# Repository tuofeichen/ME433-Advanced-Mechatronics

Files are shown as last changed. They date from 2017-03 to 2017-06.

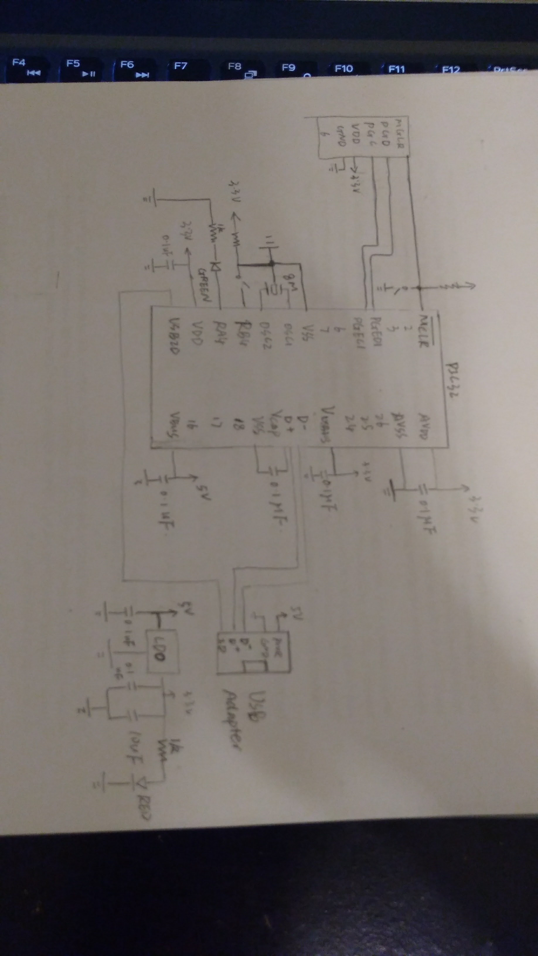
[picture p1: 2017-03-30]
HW1/HW1_Schematic.jpg

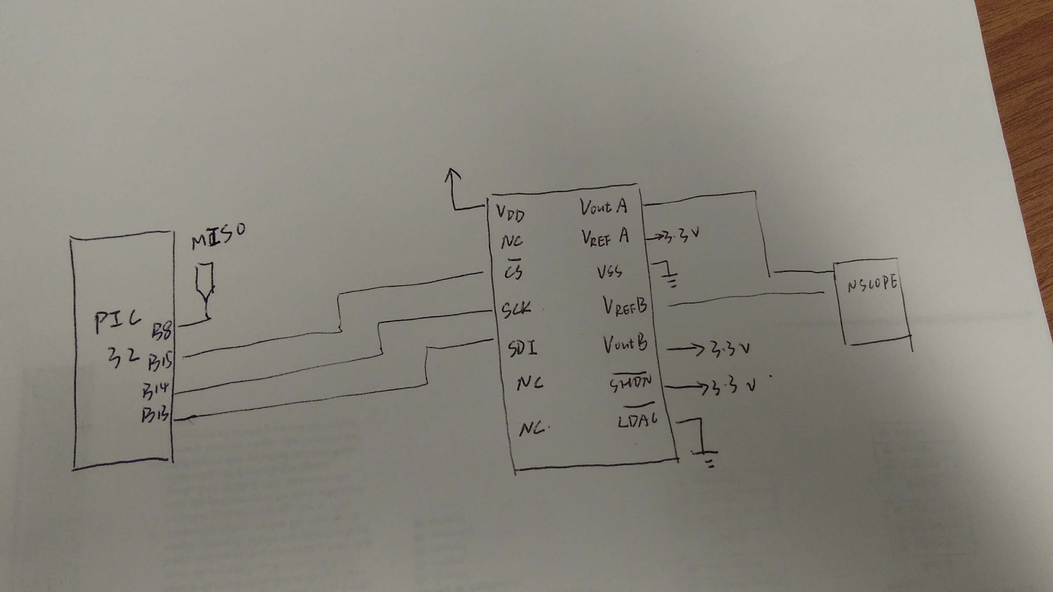
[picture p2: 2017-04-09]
HW4/dac.jpg

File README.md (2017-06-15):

# ME433-Advanced-Mechatronics
This is a course repo for ME 433 Advanced Mechatronics at Northwestern. In this class, I build a mobile robot that's controlled by an Android phone to follow a colored line. 

I use the camera of the phone to track the line and I use a PIC32 microcontroller to control the motor. The phone and the PIC32 communicates via USB. 

The final java code for the android phone is in TechCupAndroid folder while the final C code for the PIC32 is in the TechCupPIC folder. 

I laser cut and 3D printed all the mounting fixture (including suspension and wheels). 

See below as the final demonstration. 

(https://www.youtube.com/watch?v=JEivp6OKbOI)

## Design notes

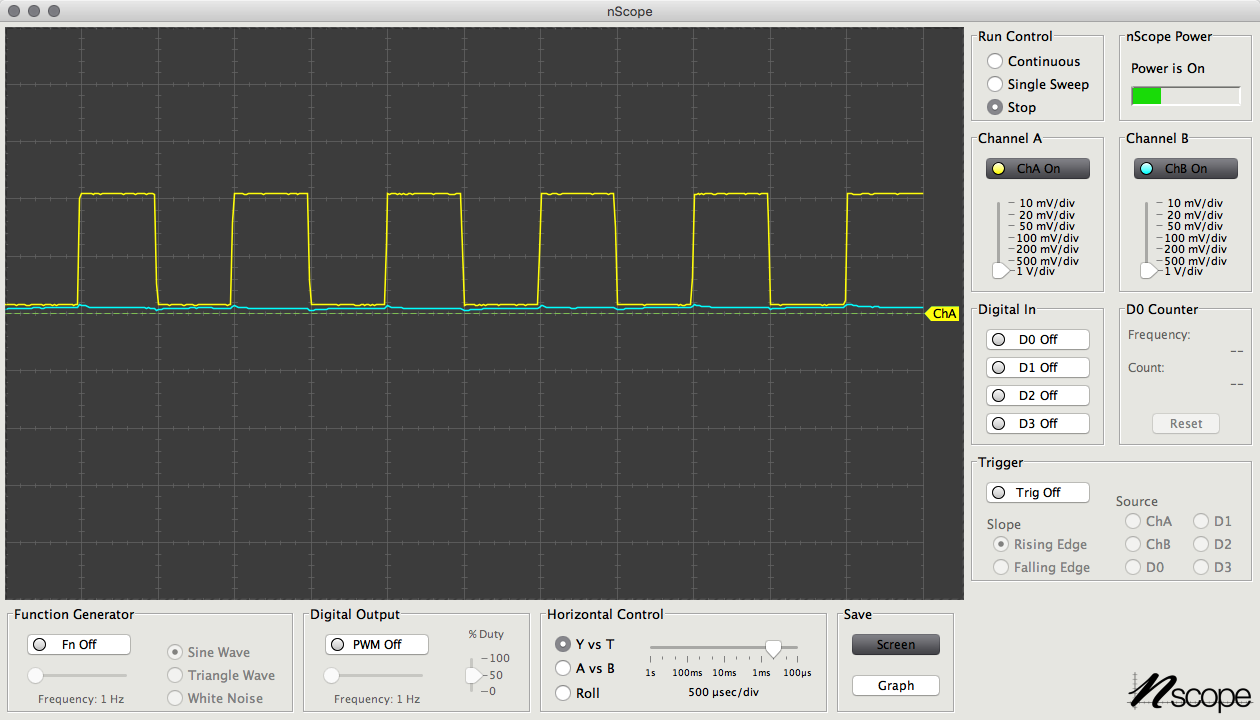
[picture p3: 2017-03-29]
HW1/HW1_LED_Signal.png

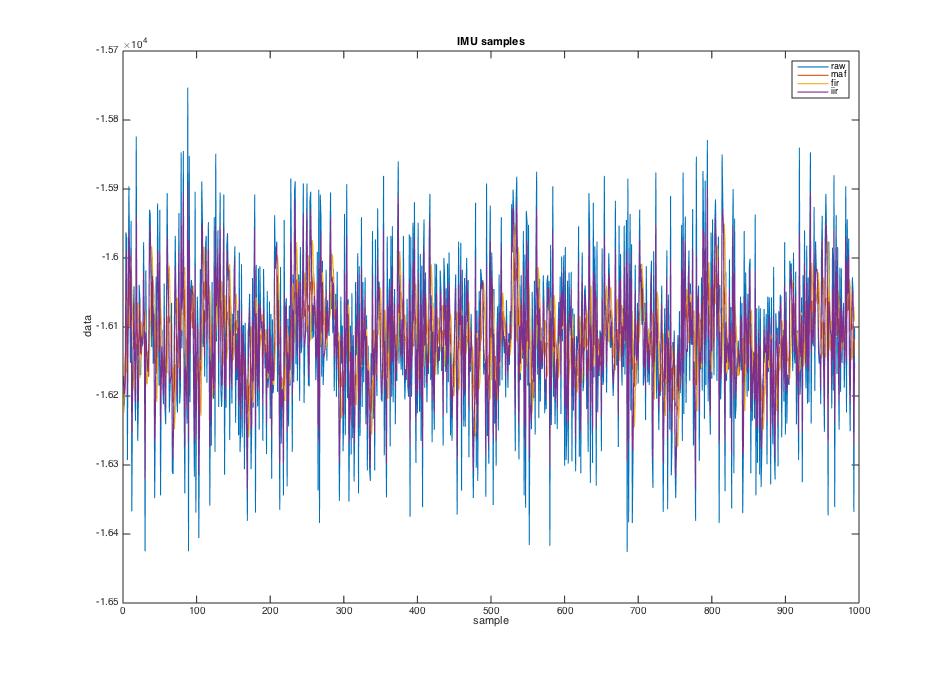
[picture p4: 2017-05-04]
HW9/all_in_one6.jpg

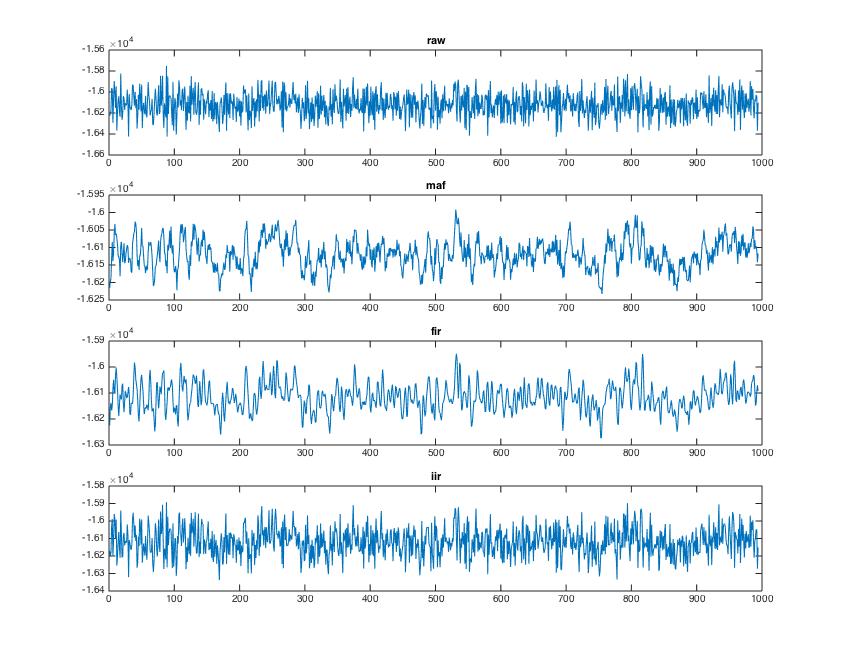
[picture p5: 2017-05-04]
HW9/sep6.jpg

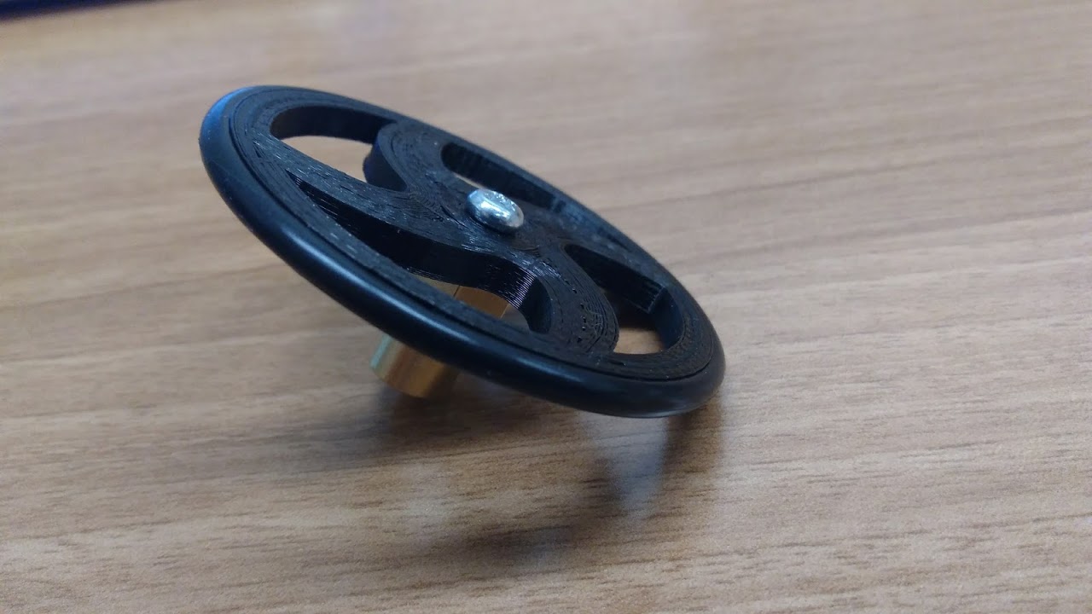
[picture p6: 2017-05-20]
HW16/wheel.jpg

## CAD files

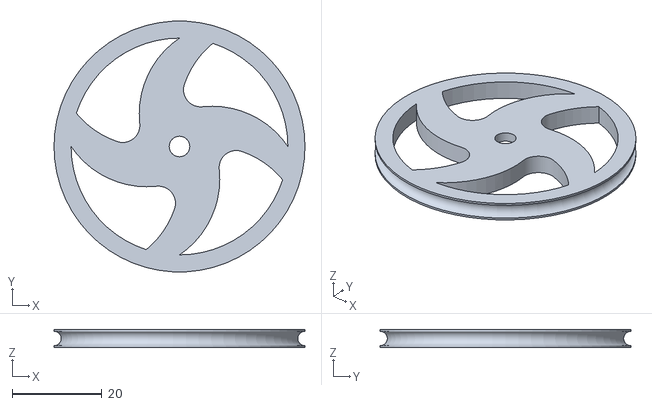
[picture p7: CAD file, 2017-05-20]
HW15/Wheel.stl
55.9 x 55.8 x 4.06

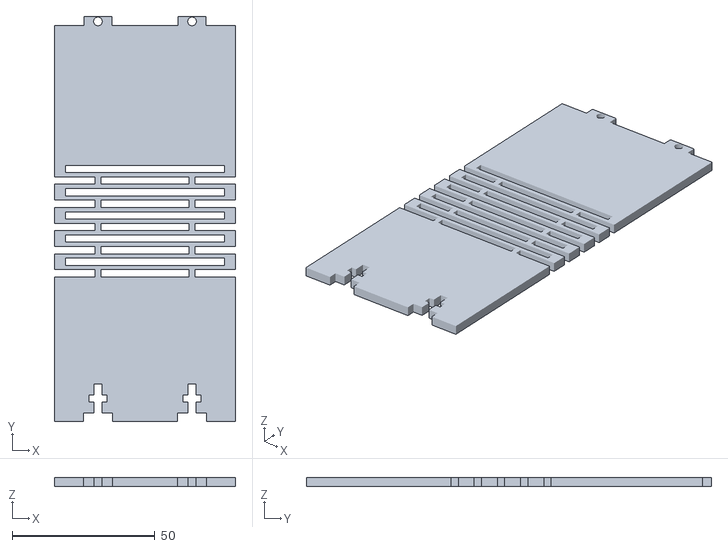
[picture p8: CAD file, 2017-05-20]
HW15/box_revolved.stl
63.5 x 142.2 x 3.17

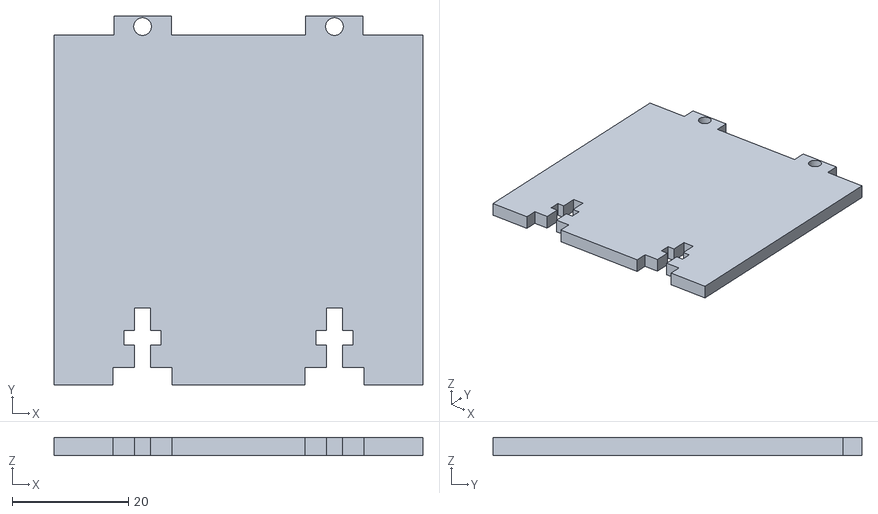
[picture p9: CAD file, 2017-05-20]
HW15/box_side.stl
63.5 x 63.5 x 3.17

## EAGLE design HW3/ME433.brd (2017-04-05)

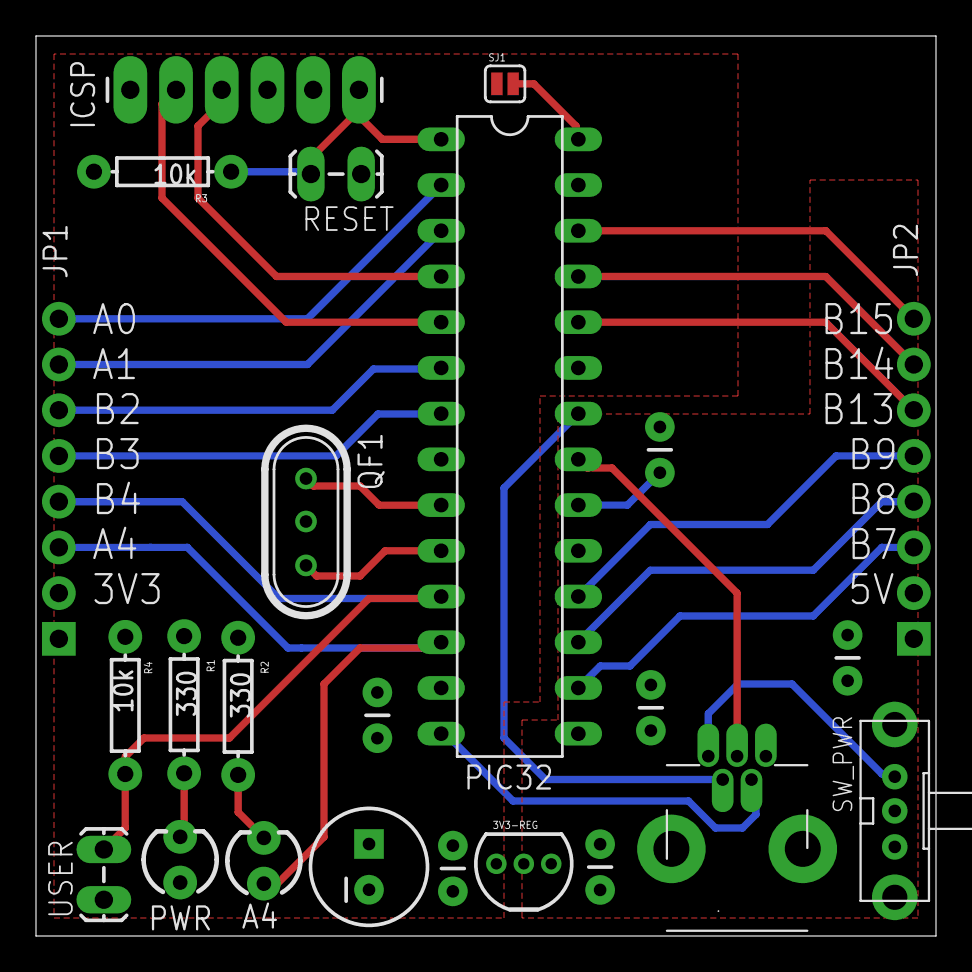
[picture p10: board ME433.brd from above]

Board: 2 copper layers, 50.0 x 50.0 mm, 24 parts (0 on the bottom side), 28 nets.

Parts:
3V3-REG: 3V3-REG-TO92; TO-92
A4: LED3MM
C1, C2, C3, C9, C10: 0.1uF; CAP-PTH-SMALL
C4: 10uF; CAP-PTH-SMALL
C6: 10uF; CPOL-RADIAL-100UF-25V
CN1: USB-MINIB-THM-MOLEX
ICSP: 1X06_LONGPADS
JP1, JP2: 1X08
PIC32: PIC32MX250F128B-DIP; DIP28
PWR: LED3MM
QF1: 8M; HC49U
R1, R2: 330; AXIAL-0.3
R3, R4: 10k; AXIAL-0.3
RESET: PUSH_BUT; 1X02_LOCK_LONGPADS
SJ1: SOLDERJUMPERNC; SJ_2S
SW_PWR: EG1213
USER: PUSH_BUT; 1X02_LOCK_LONGPADS

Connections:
5V: 3V3-REG.2, C2.1, C3.2, C9.2, JP2.2, PIC32.15, SW_PWR.2
!MCLR: ICSP.1, PIC32.1, R3.P$1, RESET.2
+3V3: 3V3-REG.1, C1.1, C6.1, C10.2, ICSP.2, JP1.2, PIC32.13, PIC32.23, PWR.A, R3.P$2, R4.P$2, SJ1.1
AVDD: PIC32.28, SJ1.2
GND: 3V3-REG.3, C1.2, C2.2, C3.1, C4.2, C6.2, C9.1, C10.1, CN1.GND, ICSP.3, JP1.1, JP2.1, PIC32.8, PIC32.19, PIC32.27, QF1.2, R1.P$1, R2.P$1, RESET.1, USER.1
unnamed: PIC32.9, QF1.1
unnamed: PIC32.10, QF1.3
unnamed: A4.K, R2.P$2
unnamed: C4.1, PIC32.20
unnamed: PWR.K, R1.P$2
unnamed: CN1.VBUS, SW_PWR.3
PGC: ICSP.5, PIC32.5
PGD: ICSP.4, PIC32.4
RA0: JP1.8, PIC32.2
RA1: JP1.7, PIC32.3
RA4: A4.A, JP1.3, PIC32.12
RB2: JP1.6, PIC32.6
RB3: JP1.5, PIC32.7
RB4: JP1.4, PIC32.11, R4.P$1, USER.2
RB7: JP2.3, PIC32.16
RB8: JP2.4, PIC32.17
RB9: JP2.5, PIC32.18
RB13: JP2.6, PIC32.24
RB14: JP2.7, PIC32.25
RB15: JP2.8, PIC32.26
USB_D+: CN1.D+, PIC32.21
USB_D-: CN1.D-, PIC32.22
USB_ID: CN1.ID, PIC32.14

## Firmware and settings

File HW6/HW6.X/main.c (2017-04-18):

#include<xc.h>           // processor SFR definitions
#include<sys/attribs.h>  // __ISR macro
#include "tft.h"

// DEVCFG0
#pragma config DEBUG  = OFF         // no debugging
#pragma config JTAGEN = OFF         // no jtag
#pragma config ICESEL = ICS_PGx1    // use PGED1 and PGEC1
#pragma config PWP    = OFF         // no write protect
#pragma config BWP    = OFF         // no boot write protect
#pragma config CP     = OFF         // no code protect

// DEVCFG1
#pragma config FNOSC    = PRIPLL       // use primary oscillator with pll
#pragma config FSOSCEN  = OFF          // turn off secondary oscillator
#pragma config IESO     = OFF          // no switching clocks
#pragma config POSCMOD  = HS           // high speed crystal mode
#pragma config OSCIOFNC = OFF          // free up secondary osc pins
#pragma config FPBDIV   = DIV_1        // divide CPU freq by 1 for peripheral bus clock
#pragma config FCKSM    = CSDCMD       // do not enable clock switch
#pragma config WDTPS    = PS1048576    // slowest wdt
#pragma config WINDIS   = OFF          // no wdt window
#pragma config FWDTEN   = OFF          // wdt off by default
#pragma config FWDTWINSZ = WINSZ_25    // wdt window at 25%

// DEVCFG2 - get the CPU clock to 48MHz
#pragma config FPLLIDIV = DIV_2     // divide input clock to be in range 4-5MHz
#pragma config FPLLMUL  = MUL_24    // multiply clock after FPLLIDIV
#pragma config FPLLODIV = DIV_2     // divide clock after FPLLMUL to get 48MHz
#pragma config UPLLIDIV = DIV_2     // divider for the 8MHz input clock, then multiply by 12 to get 48MHz for USB
#pragma config UPLLEN   = ON        // USB clock on

// DEVCFG3
#pragma config USERID       = 0x0000  // some 16bit userid, doesn't matter what
#pragma config PMDL1WAY     = OFF     // allow multiple reconfigurations
#pragma config IOL1WAY      = OFF     // allow multiple reconfigurations
#pragma config FUSBIDIO     = ON      // USB pins controlled by USB module
#pragma config FVBUSONIO    = ON      // USB BUSON controlled by USB module


volatile int i = 0;

void __ISR(_TIMER_2_VECTOR, IPL7SOFT)refreshScreen(void)
{
    char hello [100];
    sprintf(hello, "hello ME433! %d  ",i);         
    drawStr (28, 32,  hello,   0xF0E2);
    drawRect(14, 50,  i ,  20 ,0xF0E2);
    PORTAINV = 0x0010;
    if (i++ == 100)
    {
        drawRect(14 ,50,  100 ,  20 , BACKGROUND);
        i = 0;
    }           
    
    IFS0bits.T2IF = 0;          // clear interrupt flag 2!
};

int main() {

    __builtin_disable_interrupts();

    // set the CP0 CONFIG register to indicate that kseg0 is cacheable (0x3)
    __builtin_mtc0(_CP0_CONFIG, _CP0_CONFIG_SELECT, 0xa4210583);

    // 0 data RAM access wait states
    BMXCONbits.BMXWSDRM = 0x0;

    // enable multi vector interrupts
    INTCONbits.MVEC = 0x1;

    // disable JTAG to get pins back
    DDPCONbits.JTAGEN = 0;

    // do your TRIS and LAT commands here
    TRISAbits.TRISA4 = 0; //set A4 to be output (Green LED)
    TRISBbits.TRISB4 = 1; //set B4 to be input  (debug button)
    _CP0_SET_COUNT(0);
    
    SPI1_init();
    LCD_init();
    timer_init();
    
    __builtin_enable_interrupts();
    


    PORTACLR = 0x0010; // clear error flag
    LCD_clearScreen(BACKGROUND);

//    drawRect(30,50,40,20,0xF0E2);
    while(1) {           
//        int i = 0;
//        for (i = 0 ; i < 100;i++)
//        {   
//           sprintf(hello, "hello ME433! %d  ",i);
//           
//           _CP0_SET_COUNT(0);        
//            while (_CP0_GET_COUNT()< 4800000)
//            {
//                ;
//            }
//           drawStr (28, 32,  hello,   0xF0E2);
//           drawRect(14, 50,  i ,  20 ,0xF0E2);
//           
//           
//        }
//        drawRect(14 ,50,  100 ,  20 , BACKGROUND);
//        
//        if (!PORTBbits.RB4)
//        {
//            PORTACLR = 0x0010;
//        }
        
    }
}

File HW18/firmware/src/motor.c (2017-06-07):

#include "motor.h"

void motor_init()
{
    // put these initializations in APP_Initialize()
    RPA0Rbits.RPA0R = 0b0101; // A0 is OC1
    TRISAbits.TRISA1 = 0;
    LATAbits.LATA1 = 0; // A1 is the direction pin to go along with OC1

    RPB2Rbits.RPB2R = 0b0101; // B2 is OC4
    TRISBbits.TRISB3 = 0;
    LATBbits.LATB3 = 0; // B3 is the direction pin to go along with OC
    
    T2CONbits.TCKPS = 2; // prescaler N=4 
    PR2 = PERIOD - 1; // 10kHz
    TMR2 = 0;
    OC1CONbits.OCM = 0b110; // PWM mode without fault pin; other OC1CON bits are defaults
    OC4CONbits.OCM = 0b110;
    OC1RS = 0; // max allowed value is 1119
    OC1R = 0; // read-only initial value
    OC4RS = 0; // max allowed value is 1119
    OC4R = 0; // read-only initial value
    T2CONbits.ON = 1;
    OC1CONbits.ON = 1;
    OC4CONbits.ON = 1;
    
    motor_set_speed(0,0);
    motor_set_speed(1,0);
}


void motor_set_speed(int motor, int pct)
{
       // somewhere in APP_Tasks(), probably in case APP_STATE_SCHEDULE_READ
       // when you read data from the host
    if (motor == 0) // first motor 
    {
       LATAbits.LATA1 = (pct>0); // direction
       OC1RS = abs(pct); // velocity, 50%
    }
    else
    {
       LATBbits.LATB3 = (pct>0); // direction
       OC4RS = abs(pct); // velocity, 50%
    }
}

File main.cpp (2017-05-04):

#include <iostream>
#include <stdio.h>

int len(char* arr);
using namespace std;
int main()
{
 char hello [100];
 sprintf(hello,"hello world");
 cout << "length of hw is " << len(&hello) << endl;
 cout << hello  << endl; 
 return 0;
 
}

int len(char* arr)
{
 *arr++ = 'a';
 *arr++ = 'b';
 return 1;
// return strlen(arr);
}

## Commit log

2017-04-01 add pcb, update gitignore file
    [ME433.brd, ME433.sch]
2017-04-05 add gerber file for pic breakout
    [ME433.GBL, ME433.GBO, ME433.GBP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]
2017-04-05 add final board file
    [ME433.brd]
2017-04-09 circuit diagram
2017-04-11 switch to timer interrupt for the timing
2017-04-12 i2c blinker hw5
2017-04-16 fixed clear progress bar
    [main.c]
2017-04-18 fix hw6 clear interrupt flag in isr
    [main.c]
2017-04-20 imu screen code
2017-04-24 clean up imu code
2017-04-27 spi debug
2017-04-27 add dsp filters
    [imu.csv]
2017-04-27 add filtered log
    [imu.csv]
2017-05-01 add matlab utility for fft and some log data for imu output
2017-05-01 add imu plot
2017-05-02 imu based mouse
2017-05-02 refresh speed and mouse button
2017-05-11 HW13 Android Camera
2017-05-20 add cad and wheel
    [Wheel.stl, box_revolved.stl, box_side.stl]
2017-05-25 add laser cut box
2017-06-03 add motor control code

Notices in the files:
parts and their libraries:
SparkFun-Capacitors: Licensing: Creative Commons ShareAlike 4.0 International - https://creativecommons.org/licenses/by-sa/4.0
